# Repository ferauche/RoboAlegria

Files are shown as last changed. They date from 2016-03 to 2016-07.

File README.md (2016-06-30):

# RoboAlegria
Projeto de código aberto, com o objetivo de compartilhar conhecimentos sobre eletrônica, robótica e programação de computadores.

O objetivo geral do projeto é criar um Robô para ser utilizado no trabalho de ONGs como o [Doutores da Alegria](https://www.doutoresdaalegria.org.br/).

A estrutra dos diretórios está organizada para
- appInventor: código do AppInventor para testar a comunicação via bluetooth com o Robô.
- arduino: código do Arduino para o controle da expressão facial (matriz de leds)
- images: imagens utilizadas no projeto
- webservice: código da parte web para a interface que o operador controlar o robô  

Mais informações na wiki do projeto: https://github.com/ferauche/RoboAlegria/wiki

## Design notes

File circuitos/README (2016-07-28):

Alterações para próxima versão:
1 - Colocar diodo e capacitor paralelo a alimentação do servomotor para evitar instabilidades
2 - Diminuir largura da placa para ficar igual à do Arduino;
3 - Marcar no silkscreen a área ocupada pelo ESP8266;
4 - Incluir LEDs para indicação da alimentação (5V da bateria, 5V do Arduino, 3V do Arduino);
5 - Incluir botão de reset no shield (opcional)/

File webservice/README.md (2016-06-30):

O Webservice é divido em duas partes principais:  
  
* Webservice Backend  
* Interface Frontend  

##Descrição##  
  
O Webservice deve rodar em um servidor HTTP. Onde será acessado (por IP) pelo app android.
O Servidor deve armazenar um arquivo .txt e um arquivo de áudio, que serão escritos pela Interface Frontend, esses arquios serão lidos pelo app android por endereços URL específicos.

Pela Interface Frontend o controlador poderá escolher as expressões (olhos e boca) e movimentação dos braços para o robô. Quando o controlador escolhe alguma ação para o robô, o Backend escreve no arquivo .txt o código referente a ação, o app android vai ler o arquivo .txt e enviar o comano para o robô executar.  
  
O controlador tambem poderá fazer gravação de áudio que será salva em um arquivo no servidor. Quando um áudio é gravado, o Backend salva o arquivo (formato de áudio à definir), escreve no arquivo .txt, para o app android ler o arquivo de áudio e reproduzi lo.

Na Interface Frontend o controlador tambem poderá visualizar o vídeo e ouvir o áudio enviados pelo app android. O Webservice deverá acessar um endereço URL específico fornecido pelo app android para acessar o vídeo e áudio.

A Interface Frontend terá alguns campos de textos, para o controlador fazer anotações sobre a criança.
  
A Interface Frontend tem como base a imagem abaixo.  
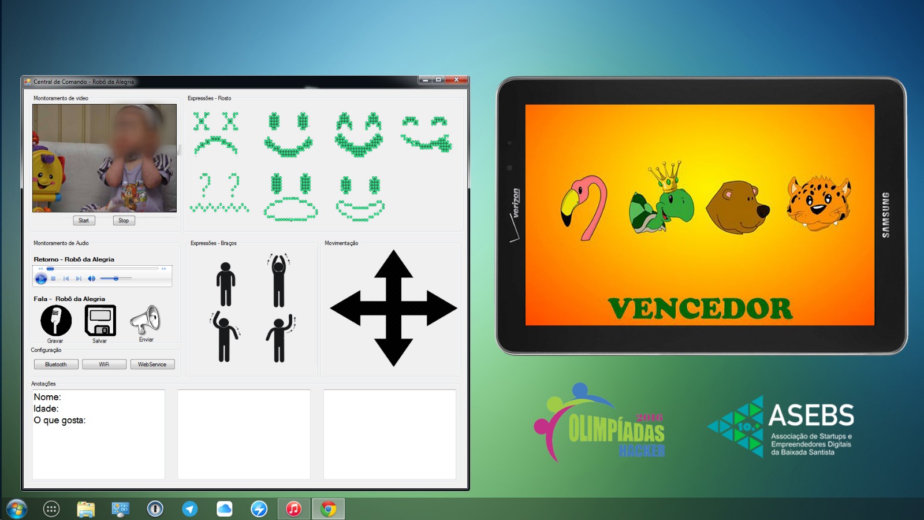
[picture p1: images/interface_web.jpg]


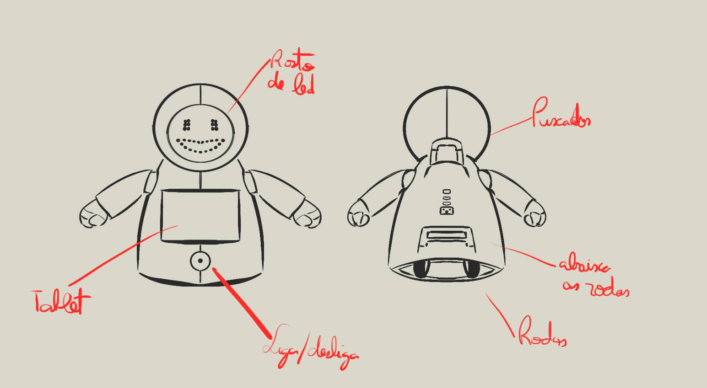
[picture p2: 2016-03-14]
images/layout.jpg

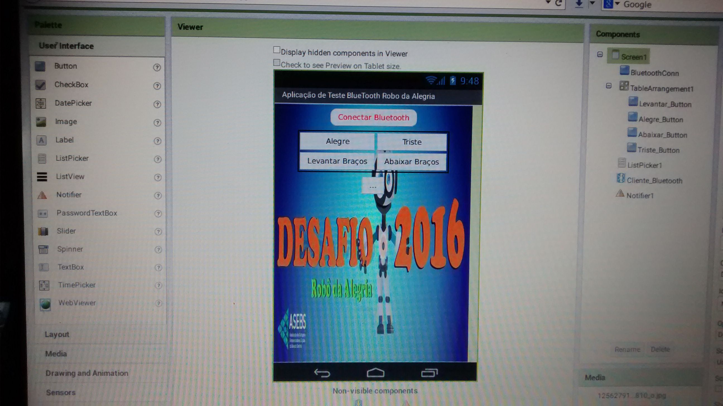
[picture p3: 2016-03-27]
images/layout_aia.jpeg

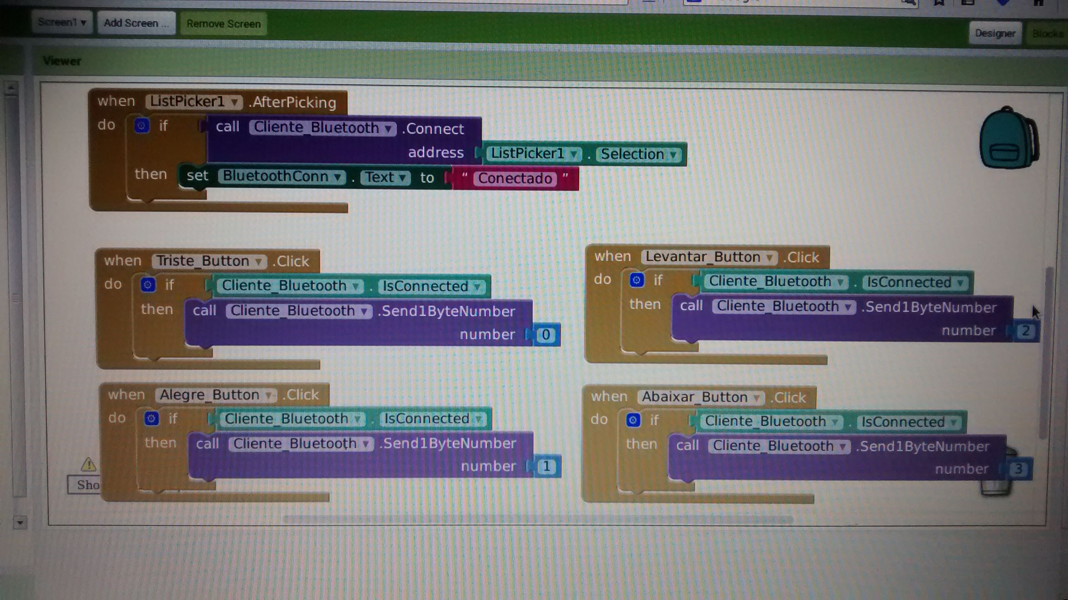
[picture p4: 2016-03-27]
images/pgm_aia.jpeg

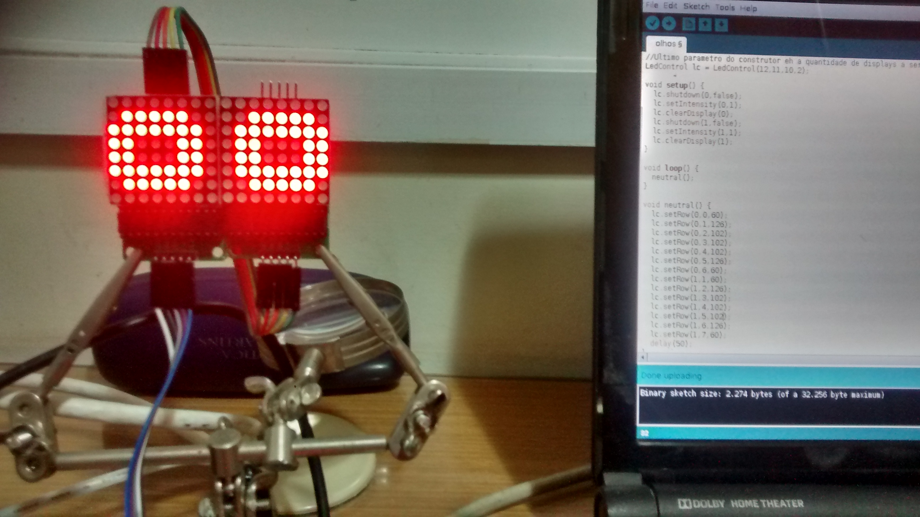
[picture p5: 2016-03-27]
images/robot_eye.jpg

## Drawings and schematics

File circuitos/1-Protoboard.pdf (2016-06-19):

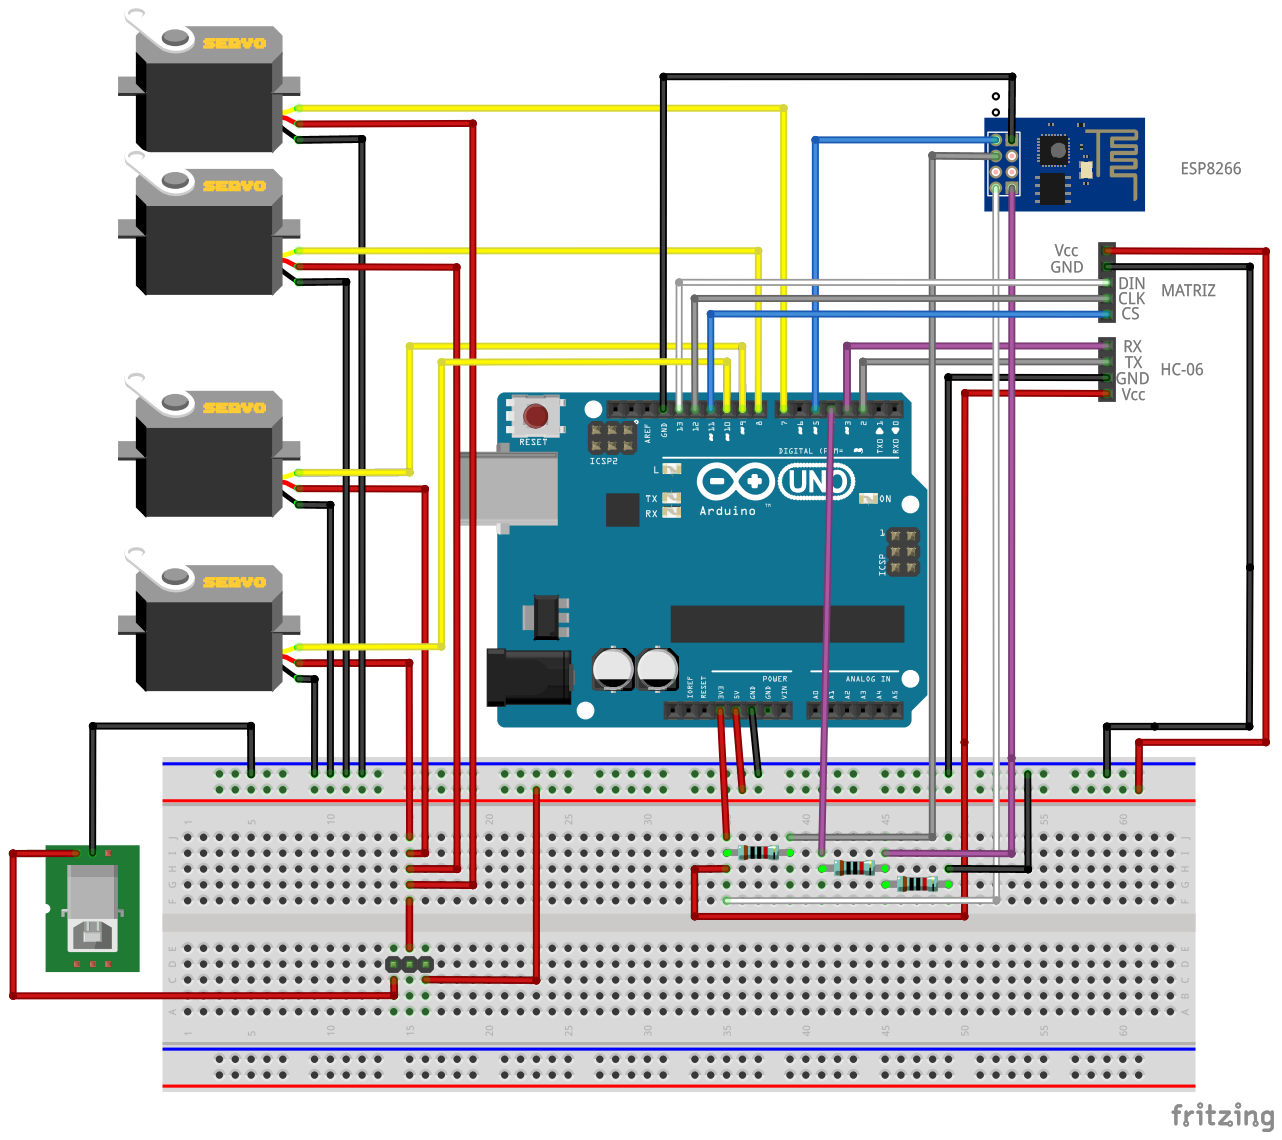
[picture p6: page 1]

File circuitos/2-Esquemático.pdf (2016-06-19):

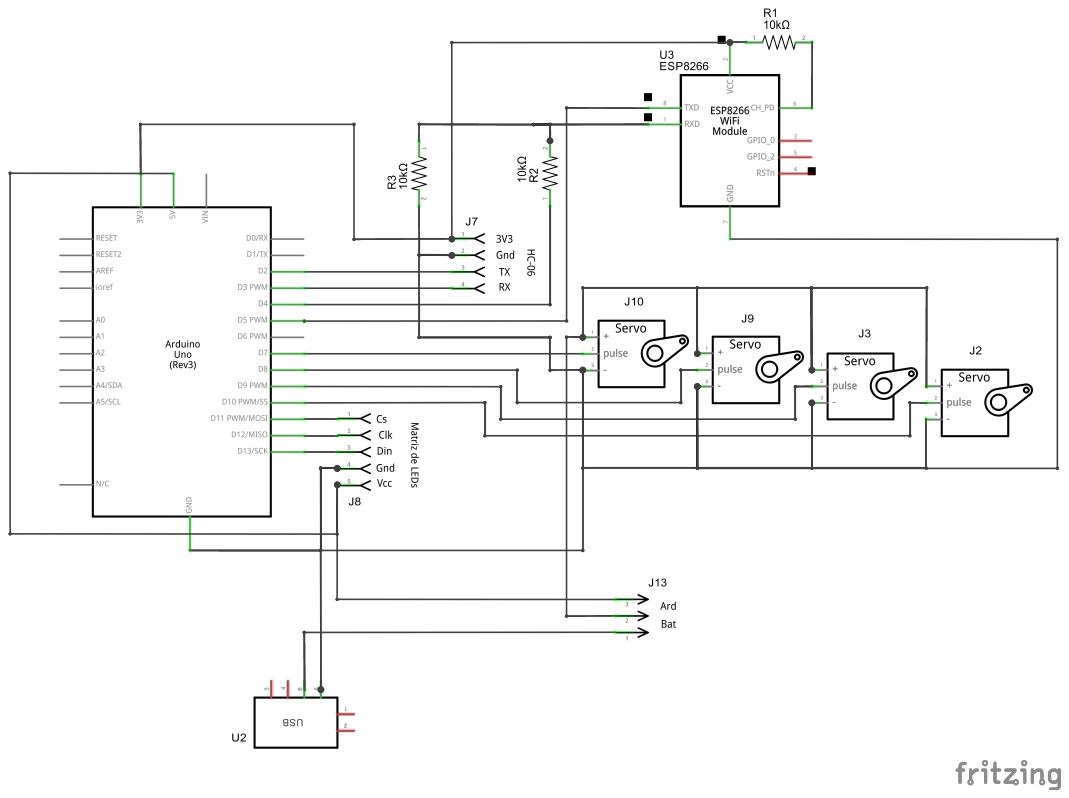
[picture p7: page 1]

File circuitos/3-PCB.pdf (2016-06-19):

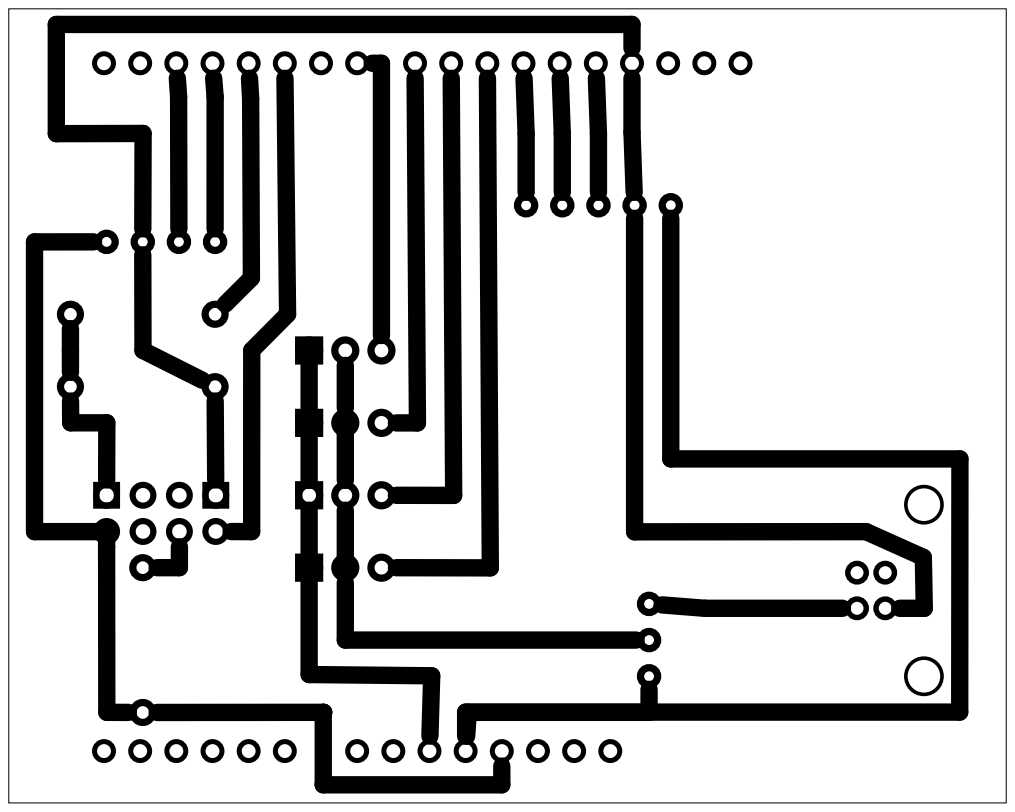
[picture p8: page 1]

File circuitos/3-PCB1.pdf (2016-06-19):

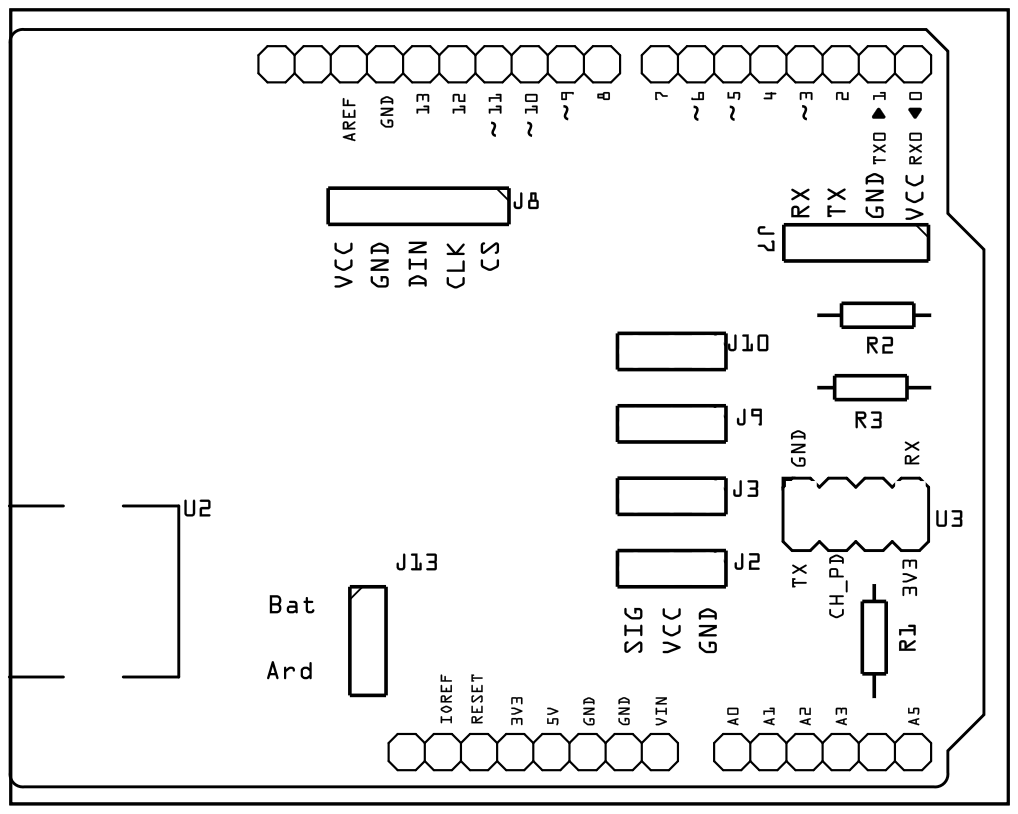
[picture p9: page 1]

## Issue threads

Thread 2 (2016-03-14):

Arduino Conexão via Bluetooth

ferauche, 2016-03-14:
Conexão do Arduino com o módulo Bluetooth HC-05

ferauche, 2016-03-14:
Conexão do Arduindo com matriz de LED max7219, para representação dos olhos.
Podendo ser como base: http://www.instructables.com/id/Animated-Halloween-Evil-Eyes/
Exemplo: https://www.youtube.com/watch?v=r8GYG0Wfa08

Closed 2016-03-14.

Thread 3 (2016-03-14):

Arduino representação Facial

ferauche, 2016-03-14:
Conexão do Arduindo com matriz de LED max7219, para representação dos olhos e Boca

Os olhos:
Podendo ser como base: http://www.instructables.com/id/Animated-Halloween-Evil-Eyes/
Exemplo: https://www.youtube.com/watch?v=r8GYG0Wfa08

ferauche, 2016-03-27:
Olhos implementados utilizando a biblioteca LedControl.h
https://github.com/wayoda/LedControl

Closed 2016-03-27.

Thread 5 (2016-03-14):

Aplicativo de Teste AppInventor

ferauche, 2016-03-14:
Utilizar o MIT Appinventor para desenvolver um aplicativo de teste de comunicação bluetooth entre um Android e Arduino.

O app deverá ter botões para enviar as mensagens abaixo no formato int:
(TRISTE=0, ALEGRE=1, LEVANTAR_BRACOS=2, ABAIXAR_BRACOS=3)

ferauche, 2016-03-16:
https://github.com/ferauche/RoboAlegria/tree/master/appInventor

Versão inicial, ainda não testada.

ferauche, 2016-04-18:
Falta adaptar as opcoes para os outros comandos.

Closed 2016-04-18.

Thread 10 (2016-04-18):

Desenhar projeto de PCB como shield

ferauche, 2016-04-18:
Seguindo esquema de ligação elétrica, desenhar uma PCB como um shield a ser conectada no Arduino UNO.

igorfonseca83, 2016-06-19:
Arquivos copiados para a pasta "circuitos".

ferauche, 2016-08-02:
Shield montado e em funcionamento pelo @igorfonseca83

Closed 2016-08-02.

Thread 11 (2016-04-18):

Aplicativo Android para fazer a ponte entre WiFi e BlueTooth

ferauche, 2016-04-18:
Aplicativo android que irá receber requisições de um outro programa via wifi, e irá traduzir essa requisição em um comando a ser enviado via BlueTooth ao Arduino.

ferauche, 2016-08-02:
Módulo HC-05 substituído pelo ESP-8266, código e conexões de hardware realizados por @igorfonseca83

Closed 2016-08-02.

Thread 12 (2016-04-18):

Atualizar wiki do projeto

ferauche, 2016-04-18:
Atualizar a wiki do projeto especialmente a página Documentação, com as alterações realizadas no código, e o funcionamento do projeto que ficou definido como meta para 2016 atuar como um "fantoche" recebendo comandos via Wi-Fi.

ferauche, 2016-04-28:
Wiki atualizada.

Closed 2016-04-28.

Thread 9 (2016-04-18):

Desenhar um esquema elétrico de ligação com o Arduino

ferauche, 2016-04-18:
Desenhar no Fritzing (http://fritzing.org) o esquemático com as ligações com as matrizes de Leds, o módulo HC-06 e os servos (com alimentação separada)

igorfonseca83, 2016-04-24:
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

ferauche, 2016-04-25:
Show, obrigado Igor!

igorfonseca83, 2016-04-25:
Estou trabalhando na PCB para fazermos a primeira versão de um shield.
Assim que estiver pronto eu compartilho.
Em 25 de abr de 2016 4:45 PM, "Thiago Ferauche" <notifications@github.com>
escreveu:

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

Closed 2016-04-25.

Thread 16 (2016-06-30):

Webservice [Frontend] - Tela de Interface com o usuário

helam01, 2016-06-30:
Desenvolver a tela de Interface, que enviará os dados para o backend.
A Interface deve ser baseada na imagem abaixo.
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

ferauche, 2016-08-02:
@igorfonseca83 poderia mandar um pullrequest com o código da página que contém a interface, e o código usando JQUERY para mandar os requests ao webservice?

Closed 2016-09-20.

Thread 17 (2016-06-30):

Webservice [Backend] - Receber os dados do Frontend e salvar o .txt e áudio

helam01, 2016-06-30:
O backend deve configurado para rodar em um servidor local.

* Deve receber os dados enviados pelo Frontend.
* Salvar os comandos no arquios .txt
* Salvar o arquivo de áudio, quando solicitado.
* Configurar as URLs de rotas para disponibilizar os arquivos .txt e de áudio.

Closed 2016-09-20.

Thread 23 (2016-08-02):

Bluetooth e Wifi opcionais

ferauche, 2016-08-02:
Realizar alteraçoes de hardware (no shield) e no código, para deixar a conexão configurável, como uma opção para o usuário utilizar a conexão bluetooth ou wifi.

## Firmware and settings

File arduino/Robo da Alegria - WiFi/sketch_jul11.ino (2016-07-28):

// Robô da Alegria v1.0 By Igor Fonseca Albuquerque
// Faces por Thiago Farauche e Diego Augustus

//incluir bibliotecas
#include <SoftwareSerial.h>
#include <Servo.h>
#include "LedControl.h"

LedControl lc = LedControl(13,12,11,5); //Pinos 13 (DIN), 12 (CLK), 11 (CS), 5 displays a serem controlados
SoftwareSerial esp8266(5, 4); //RX pino 5, TX pino 4

//definição de variáveis 
#define DEBUG true //exibir mensagens trocadas entre o ESP8266 e o arduino na porta Serial
#define SERV1 9 //porta digital 9 PWM
#define SERV2 10 //porta digital 10 PWM
#define SERV3 8 //porta digital 8 PWM
#define SERV4 7 //porta digital 7 PWM

Servo s1; //servo 1
Servo s2; //servo 2
Servo s3; //servo 3
Servo s4; //servo 4
int pos1 = 170; //ângulo atual do servo 1
int pos2 = 170; //ângulo atual do servo 2
int pos3 = 15; //ângulo atual do servo 3
int pos4 = 15; //ângulo atual do servo 4
int vel = 10; //velocidade dos servos (100 -> 90º em 1 s)(1 -> 90º em 9 s)
int pos1min = 20; //ângulo mínimo do servo 1
int pos2min = 20; //ângulo mínimo do servo 2
int pos3min = 40; //ângulo mínimo do servo 3
int pos4min = 40; //ângulo mínimo do servo 4
int pos1max = 160; //ângulo máximo do servo 1
int pos2max = 160; //ângulo máximo do servo 2
int pos3max = 160; //ângulo máximo do servo 3
int pos4max = 160; //ângulo máximo do servo 4
int face; //número da face atual
boolean piscar; //definir se deve ou não piscar os olhos
byte olho_atual[8];
unsigned long tempo0; //tempo para piscar os olhos


//*******************
//definição dos olhos
//*******************

//olho morto
byte olho_x[8] = { B00000000,
                   B01100110,
                   B00100100,
                   B00011000,
                   B00011000,
                   B00100100,
                   B01100110,
                   B00000000};

//olho interrogação
byte olho_int[8] = {B00011000,
                    B00100100,
                    B00000100,
                    B00000100,
                    B00001000,
                    B00010000,
                    B00000000,
                    B00010000};

//olho neutro                   
byte olho_neutro[8] = {B00000000,
                       B00011000,
                       B00111100,
                       B00111100,
                       B00111100,
                       B00111100,
                       B00011000,
                       B00000000};

//olho arregalado
byte olho_arregalado[8] = {B00011000,
                           B00111100,
                           B00111100,
                           B00111100,
                           B00111100,
                           B00111100,
                           B00111100,
                           B00011000};

//olho fechado (para cima)
byte olho_fechado[8] = {B00000000,
                        B00000000,
                        B00000000,
                        B00111100,
                        B01111110,
                        B01100110,
                        B00000000,
                        B00000000};

//olho fechado (para baixo)
byte olho_dormindo[8] = {B00000000,
                          B00000000,
                          B00000000,
                          B01100110,
                          B01111110,
                          B00011000,
                          B00000000,
                          B00000000};                        
                        
//*****************
//definição da boca
//*****************

//boca alegre fechada                        
byte boca_alegre[24] = { B00000000,
                         B00001000,
                         B00011100,
                         B00011110,
                         B00001111,
                         B00000011,
                         B00000000,
                         B00000000,
                         // parte1
                         B00000000,
                         B00000000,
                         B00000000,
                         B00000000,
                         B10000001,
                         B11111111,
                         B11111111,
                         B01111110,
                         // parte2
                         B00000000,
                         B00010000,
                         B00111000,
                         B01111000,
                         B11110000,
                         B11000000,
                         B00000000,
                         B00000000 };


//boca triste fechada
byte boca_triste[24] = { B00000000,
                         B00000000,
                         B00000000,
                         B00000011,
                         B00001111,
                         B00011000,
                         B00010000,
                         B00000000,
                         // parte1
                         B00000000,
                         B00111100,
                         B11111111,
                         B11000011,
                         B00000000,
                         B00000000,
                         B00000000,
                         B00000000,
                         // parte2
                         B00000000,
                         B00000000,
                         B00000000,
                         B11000000,
                         B11100000,
                         B00110000,
                         B00010000,
                         B00000000 };

//boca triste aberta                         
byte aberta_triste[24] = { B00000000,
                           B00000011,
                           B00001100,
                           B00010000,
                           B00100000,
                           B00100000,
                           B00011100,
                           B00000011,
                         // parte1
                         B01111110,
                         B10000001,
                         B00000000,
                         B00000000,
                         B00000000,
                         B00000000,
                         B00000000,
                         B11111111,
                         // parte2
                         B00000000,
                         B11000000,
                         B00110000,
                         B00001000,
                         B00000100,
                         B00000100,
                         B00111000,
                         B11000000 };

//boca alegre aberta                         
byte aberta_alegre[24] = { B00000000,
                           B00011000,
                           B00100111,
                           B00100000,
                           B00010000,
                           B00001100,
                           B00000011,
                           B00000000,
                         // parte1
                         B00000000,
                         B00000000,
                         B00000011,
                         B11111100,
                         B00000000,
                         B00000000,
                         B00000011,
                         B11111100,
                         // parte2
                         B00000000,
                         B00110000,
                         B11001000,
                         B00001000,
                         B00010000,
                         B01100000,
                         B10000000,
                         B00000000 };                         

//boca do nojo                         
byte boca_nojo[24] = { B00000000,
                       B00000000,
                       B00001000,
                       B01010101,
                       B00100010,
                       B00000000,
                       B00000000,
                       B00000000,
                         // parte1
                         B00000000,
                         B00000000,
                         B10001000,
                         B01010101,
                         B00100010,
                         B00000000,
                         B00000000,
                         B00000000,
                         // parte2
                         B00000000,
                         B00000000,
                         B01000100,
                         B10101010,
                         B00010001,
                         B00000000,
                         B00000000,
                         B00000000 };                          

//boca com língua para fora
byte boca_lingua[24] = { B00000000,
                         B00011000,
                         B00001110,
                         B00000111,
                         B00000001,
                         B00000000,
                         B00000000,
                         B00000000,
                         // parte1
                         B00000000,
                         B00000000,
                         B00000000,
                         B11000011,
                         B11111111,
                         B00111100,
                         B00000000,
                         B00000000,
                         // parte2
                         B00000000,
                         B00011000,
                         B01110000,
                         B11111000,
                         B11111100,
                         B01111100,
                         B00111000,
                         B00000000 };

//boca dormindo (sorriso pequeno)
byte boca_dormindo[24] = { B00000000,
                         B00000000,
                         B00000001,
                         B00000001,
                         B00000000,
                         B00000000,
                         B00000000,
                         B00000000,
                         // parte1
                         B00000000,
                         B00000000,
                         B10000001,
                         B11111111,
                         B01111110,
                         B00000000,
                         B00000000,
                         B00000000,
                         // parte2
                         B00000000,
                         B00000000,
                         B10000000,
                         B10000000,
                         B00000000,
                         B00000000,
                         B00000000,
                         B00000000 };

//************************
//inicialização do Arduino
//************************
void setup()
{
  //inicialização dos displays (configurar intensidade e zerar os displays)
  lc.shutdown(0,false);
  lc.setIntensity(0,1);
  lc.clearDisplay(0);
  lc.shutdown(1,false);
  lc.setIntensity(1,1);
  lc.clearDisplay(1);
  lc.shutdown(2,false);
  lc.setIntensity(2,1);
  lc.clearDisplay(2);
  lc.shutdown(3,false);
  lc.setIntensity(3,1);
  lc.clearDisplay(3);
  lc.shutdown(4,false);
  lc.setIntensity(4,1);
  lc.clearDisplay(4);

  //manter o rosto dormindo durante a inicialização (até conectar com o wifi)
  fac8();

  //inicialização dos braços
  //associar os servomotores
  s1.attach(SERV1);
  s2.attach(SERV2);
  s3.attach(SERV3);
  s4.attach(SERV4);
  //posicionar os braços na posição neutra
  s1.write(pos1max);
  s2.write(pos2max);
  s3.write(pos3min);
  s4.write(pos4min);
  //desassociar os servomotores
  s1.detach();
  s2.detach();
  s3.detach();
  s4.detach();
  
  //inicialização da comunicação serial
  Serial.begin(9600);
  esp8266.begin(19200);
  
  sendData("AT+RST\r\n", 2000, DEBUG); //resetar módulo
  sendData("AT+CWMODE=1\r\n", 1000, DEBUG); //setar modo station
//  sendData("AT+CWJAP=\"Connectify-me\",\"12345678\"\r\n", 2000, DEBUG);   //conectar com a rede wifi
  sendData("AT+CWJAP=\"Thaiane\",\"1391162683\"\r\n", 2000, DEBUG);   //conectar com a rede wifi
  while(!esp8266.find("OK")) { //aguardar estabelecer conexão
  } 
  sendData("AT+CIFSR\r\n", 1000, DEBUG); //mostrar endereco IP
  sendData("AT+CIPMUX=1\r\n", 1000, DEBUG); //configura para multiplas conexões
  sendData("AT+CIPSERVER=1,80\r\n", 1000, DEBUG); // Inicia o web server na porta 80
  
  //ativar rosto alegre após conexão com o wifi
  fac1();

  //inicializar timer
  tempo0 = millis();
}

//*************************
//Loop principal do Arduino
//*************************
void loop()
{
  int delta = millis() - tempo0;
  if(delta > 3000) {              //se o tempo for superior a 10 segundos
    if(piscar == true) {
      display_olhos(olho_dormindo);  //piscar olhos
      delay(200);
      switch (face){
        case 1:
          fac1();
          break;
        case 2:
          fac2();
          break;
        case 3:
          fac3();
          break;
        case 4:
          fac4();
          break;
        case 5:
          fac5();
          break;
        case 6:
          fac6();
          break;
        case 7:
          fac7();
          break;
        case 8:
          fac8();
          break;
        case 9:
          fac9();
          break;          
      }  
      tempo0 = millis();
    }
  }
  
  if (esp8266.available())  //verifica se o ESP8266 está recebendo dados
  {
    if (esp8266.find("+IPD,")) //se tiver recebido um dado
    {
      String msg;
      esp8266.find("?"); //corre o cursor até encontrar o comando na mensagem recebida     
      msg = esp8266.readStringUntil(' '); //ler string até o fim da mensagem
      String comando = msg.substring(0, 3); //primeiros 3 caracteres da mensagem = comando
      String valorStr = msg.substring(4);   //3 caracteres seguintes = valor associado ao comando
      int valor = valorStr.toInt();         //conversão de valor para inteiro
      if (DEBUG) {
        Serial.println(comando);
        Serial.println(valor);
      }
      delay(100);
      
      //*********************************************************
      //realizar ações: movimentar servos para ângulos informados
      //*********************************************************
      
      //mover o servo1 no angulo recebido em valor
      if(comando == "sr1") {
         //limitar o angulo de entrada
         if (valor >= pos1max) {
           valor = pos1max;
         }
         if (valor <= pos1min) {
           valor = pos1min;
         }
         s1.attach(SERV1); //associar servo
         //avançar até o ângulo desejado
         while(pos1 != valor) {
           if (pos1 > valor) {
             pos1 -= 1;
             s1.write(pos1);
             delay(100/vel);
           }
           if (pos1 < valor) {
             pos1 += 1;
             s1.write(pos1);
             delay(100/vel);
           }
         }
         s1.detach(); //desassociar servo
      }

      //mover o servo2 no angulo recebido em valor
      if(comando == "sr2") {
         //limitar o angulo de entrada
         if (valor >= pos2max) {
           valor = pos2max;
         }
         if (valor <= pos2min) {
           valor = pos2min;
         }
         s2.attach(SERV2);
         while(pos2 != valor) {
           if (pos2 > valor) {
             pos2 -= 1;
             s2.write(pos2);
             delay(100/vel);
           }
           if (pos2 < valor) {
             pos2 += 1;
             s2.write(pos2);
             delay(100/vel);
           }
         }   
         s2.detach();     
      }
      
      //mover o servo3 no angulo recebido em valor
      if(comando == "sr3") {
         //limitar o angulo de entrada
         if (valor >= pos3max) {
           valor = pos3max;
         }
         if (valor <= pos3min) {
           valor = pos3min;
         }
         s3.attach(SERV3);
         while(pos3 != valor) {
           if (pos3 > valor) {
             pos3 -= 1;
             s3.write(pos3);
             delay(100/vel);
           }
           if (pos3 < valor) {
             pos3 += 1;
             s3.write(pos3);
             delay(100/vel);
           }
         }   
         s3.detach();     
      }
      
      //mover o servo4 no angulo recebido em valor
      if(comando == "sr4") {
         //limitar o angulo de entrada
         if (valor >= pos4max) {
           valor = pos4max;
         }
         if (valor <= pos4min) {
           valor = pos4min;
         }        
         s4.attach(SERV4);
         while(pos4 != valor) {
           if (pos4 > valor) {
             pos4 -= 1;
             s4.write(pos4);
             delay(100/vel);
           }
           if (pos4 < valor) {
             pos4 += 1;
             s4.write(pos4);
             delay(100/vel);
           }
         }   
         s4.detach();     
      }


      //**************************************
      //realizar ações: movimentos programados
      //**************************************

      if(comando == "mov") {
         //associar servos
        s1.attach(SERV1);
        s2.attach(SERV2);
        s3.attach(SERV3);
        s4.attach(SERV4);

        if(valor == 10) {
            mov1(); //movimento1 = levantar braço esquerdo
        }
        if(valor == 20) {
            mov2(); //movimento2 = levantar braço direito
        }
        if(valor == 30) {
            mov3(); //movimento3 = levantar os dois braços
        }
        if(valor == 40) {
            mov4(); //movimento4 = abaixar os dois braços
        }
        if(valor == 50) {
            mov5(); //movimento5 = balançar os dois braços abertos
        }
        if(valor == 60) {
            mov6(); //movimento6 = balançar os dois braços na frente
        }
        if(valor == 70) {
            mov7(); //movimento7 = balançar os dois braços na frente
        }
        if(valor == 80) {
            mov8(); //movimento8 = girar os braços
        }        
        if(valor == 90) {
            mov9(); //movimento 9 = aceno
        }
 
        //desassociar servos
        s1.detach();
        s2.detach();
        s3.detach();
        s4.detach();
      }
      
      //**********************************
      //realizar ações: movimentos da face
      //**********************************

      if(comando == "fac") {
        if(valor == 10) {
          fac1();
        }
        if(valor == 20) {
          fac2();
        }
        if(valor == 30) {
          fac3();
        }
        if(valor == 40) {
          fac4();
        }
        if(valor == 50) {
          fac5();
        }
        if(valor == 60) {
          fac6();
        }
        if(valor == 70) {
          fac7();
        }
        if(valor == 80) {
          fac8();
        }
        if(valor == 90) {
          fac9();
        }  
      }

      //procurar comando para acionar algum pino   
      /*if(comando=="pin"){ // corre o cursor até encontrar "pin=" na mensagem recebida     
          digitalWrite(valor, !digitalRead(valor)); // toggle
      } */      
    }
  }
}


//******************
//Funções auxiliares
//******************


//enviar dados para o ESP8266
String sendData(String command, const int timeout, boolean debug)
{
  String response = "";
  esp8266.print(command);
  long int time = millis();
  while ( (time + timeout) > millis())
  {
    while (esp8266.available()) //enquanto o ESP8266 tiver dados disponíveis na sua saída
    {
      char c = esp8266.read(); //ler e armazenar os caracteres recebidos
      response += c;
    }
  }
  if (debug) //se estiver em modo DEBUG, imprimir a resposta
  {
    Serial.print(response);
  }
  return response;
}


//alterar exibição dos olhos
void display_olhos(byte olhos[]) {
  for(int i=0;i<8;i++) {
   lc.setColumn(0,i,olhos[i]);
   lc.setColumn(1,i,olhos[i]);
  } 
}


//alterar exibição da boca
void display_boca(byte boca[]) {
  for(int i=0;i<8;i++) {
    lc.setColumn(2,i,boca[i]);
    lc.setColumn(3,i,boca[i+8]);
    lc.setColumn(4,i,boca[i+16]);
  }
}


//movimento1 = levantar braço esquerdo
void mov1()
{
  pos1 = pos1max;
  s1.write(pos1);        
  while(pos2 != pos2min) {
    pos2 -= 1;
    s2.write(pos2);
    delay(100/vel);
    if (pos2 < pos2min) {
      pos2 = pos2min;
    }
  }  
}


//movimento2 = levantar braço direito
void mov2()
{
  pos3 = pos3min;
  s3.write(pos3);        
  while(pos4 != pos4max) {
    pos4 += 1;
    s4.write(pos4);
    delay(100/vel);
    if (pos4 > pos4max) {
      pos4 = pos4max;
    }
  }  
}


//movimento3 = levantar os dois braços
void mov3()
{
  pos1 = pos1max;
  pos3 = pos3min;
  s1.write(pos1);        
  s3.write(pos3);        
  while((pos2 != pos2min) || (pos4!= pos4max)) {
    pos2 -= 1;
    pos4 += 1;
    s2.write(pos2);
    s4.write(pos4);
    delay(100/vel);
    if (pos2 < pos2min) {
      pos2 = pos2min;
    }
    if (pos4 > pos4max) {
      pos4 = pos4max;
    }
  }  
}


//movimento4 = abaixar os dois braços
void mov4()
{  
  pos1 = pos1max;
  pos3 = pos3min;
  s1.write(pos1);        
  s3.write(pos3);        
  while((pos2 != pos2max) || (pos4!= pos4min)) {
    pos2 += 1;
    pos4 -= 1;
    s2.write(pos2);
    s4.write(pos4);
    delay(100/vel);
    if (pos2 > pos2max) {
      pos2 = pos2max;
    }
    if (pos4 < pos4min) {
      pos4 = pos4min;
    }
  }  
}


//movimento5 = balançar os dois braços abertos
void mov5()
{
    s1.write(pos1max);
    s2.write(pos2max);
    s3.write(pos3min);    
    s4.write(pos4min);    
    delay(500);
    for(int k = 1; k < 3 ; k++) {
      while((pos1 != pos1min)&& (pos3!= pos3max)) {
        pos1 -= 1;
        pos3 += 1;
        s1.write(pos1);
        s3.write(pos3);
        delay(100/vel);
        if (pos1 < pos1min) {
          pos1 = pos1min;
        }
        if (pos3 > pos3max) {
          pos3 = pos3max;
        }
      }
      while((pos1 != pos1max)&& (pos3!= pos3min)) {
        pos1 += 1;
        pos3 -= 1;
        s1.write(pos1);
        s3.write(pos3);
        delay(100/vel);
        if (pos1 > pos1max) {
          pos1 = pos1max;
        }
        if (pos3 < pos3min) {
          pos3 = pos3min;
        }
      }
    }
}
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

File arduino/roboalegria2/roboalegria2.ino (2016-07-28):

/* Projeto de código aberto, com o objetivo de compartilhar conhecimentos sobre eletrônica, robótica e programação de computadores.

O objetivo geral do projeto é criar um Robô para ser utilizado no trabalho de ONGs como o Doutores da Alegria. */

#include <Servo.h>
#include "LedControl.h"
#include <SoftwareSerial.h>

//Pinos 12 (DIN), 11 (CLK), 10 (CS)
//Ultimo parametro do construtor eh a quantidade de displays a serem controlados
LedControl lc = LedControl(12,11,10,5);

//Defino os pino Rx pino 2 e Tx pino 3
SoftwareSerial bluetooth(2, 3);

// Braço Esquerdo
Servo servoE;

// Braço Direito
Servo servoD;

// unsigned long tempo = 1500; - não vi aplicação no código upado no github por isso comentei

byte olho_x[8] = { B00000000,
                   B01100110,
                   B00100100,
                   B00011000,
                   B00011000,
                   B00100100,
                   B01100110,
                   B00000000 };

byte olho_interrogacao[8] = { B00011000,
                    	      B00100100,
                    	      B00000100,
                    	      B00000100,
                   	      B00001000,
                    	      B00010000,
                   	      B00000000,
                              B00010000 };
                   
byte olho_neutro[8] = { B00000000,
                        B00011000,
                        B00111100,
                        B00111100,
                        B00111100,
                        B00111100,
                        B00011000,
                        B00000000 };
                  
byte olho_arregalado[8] = { B00011000,
                            B00111100,
                            B00111100,
                            B00111100,
                            B00111100,
                            B00111100,
                            B00111100,
                            B00011000 };

byte olho_fechado[8] = { B00000000,
                         B00000000,
                         B00000000,
                         B00111100,
                         B01111110,
                         B01100110,
                         B00000000,
                         B00000000 };
                        
byte boca_alegre[24] = { B00000000,
                         B00001000,
                         B00011100,
                         B00011110,
                         B00001111,
                         B00000011,
                         B00000000,
                         B00000000,
                         // parte1
                         B00000000,
                         B00000000,
                         B00000000,
                         B00000000,
                         B10000001,
                         B11111111,
                         B11111111,
                         B01111110,
                         // parte2
                         B00000000,
                         B00010000,
                         B00111000,
                         B01111000,
                         B11110000,
                         B11000000,
                         B00000000,
                         B00000000 };

byte boca_triste[24] = { B00000000,
                         B00000000,
                         B00000000,
                         B00000011,
                         B00001111,
                         B00011000,
                         B00010000,
                         B00000000,
                         // parte1
                         B00000000,
                         B00111100,
                         B11111111,
                         B11000011,
                         B00000000,
                         B00000000,
                         B00000000,
                         B00000000,
                         // parte2
                         B00000000,
                         B00000000,
                         B00000000,
                         B11000000,
                         B11100000,
                         B00110000,
                         B00010000,
                         B00000000 };
                         
byte aberta_triste[24] = { B00000000,
                           B00000011,
                           B00001100,
                           B00010000,
                           B00100000,
                           B00100000,
                           B00011100,
                           B00000011,
                           // parte1
                           B01111110,
                           B10000001,
                           B00000000,
                           B00000000,
                           B00000000,
                           B00000000,
                           B00000000,
                           B11111111,
                           // parte2
                           B00000000,
                           B11000000,
                           B00110000,
                           B00001000,
                           B00000100,
                           B00000100,
                           B00111000,
                           B11000000 };
                         
byte aberta_alegre[24] = { B00000000,
                           B00011000,
                           B00100111,
                           B00100000,
                           B00010000,
                           B00001100,
                           B00000011,
                           B00000000,
                         // parte1
                           B00000000,
                           B00000000,
                           B00000011,
                           B11111100,
                           B00000000,
                           B00000000,
                           B00000011,
                           B11111100,
                         // parte2
                           B00000000,
                           B00110000,
                           B11001000,
                           B00001000,
                           B00010000,
                           B01100000,
                           B10000000,
                           B00000000 };
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

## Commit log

2016-03-25 Inclusao olhos arduino
2016-03-27 Imagens para Doc
2016-03-30 #Servo Motores - Teste de interação dos servos com bluetooth
2016-04-10 Teste de integração dos servos motores com as matrizes de leds
2016-06-02 incluido novo código arduino, com base nos rostos usados pelo Diego
2016-06-19 Circuitos
    Esquemático e imagens das montagem do shield rev.0
2016-07-09 Mudanças pinos, mudança módulo bluetooth do HC06 PARA HC05, mudanças no código comentadas
    [mudancas-layout.fzz]
2016-07-27 Arduino - WiFi
    Código para controle dos braços e da face pelo wi-fi
